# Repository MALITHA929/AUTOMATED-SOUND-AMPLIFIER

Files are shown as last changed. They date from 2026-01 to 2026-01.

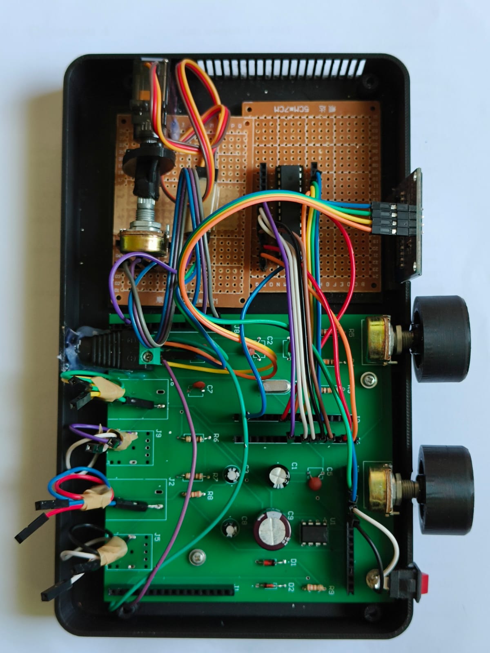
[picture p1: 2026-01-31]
images/WhatsApp Image 2026-01-30 at 5.55.49 PM.jpeg

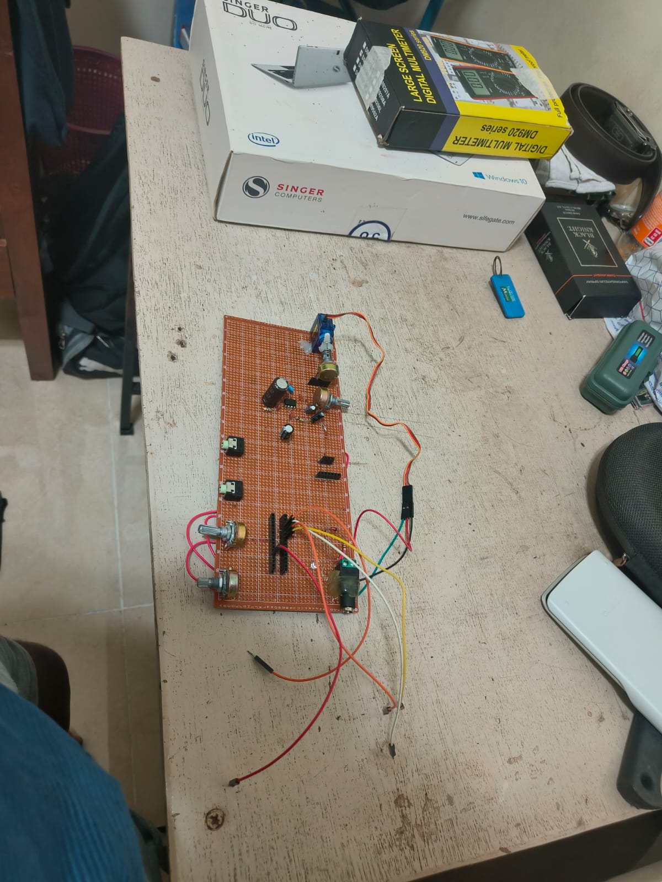
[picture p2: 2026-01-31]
images/WhatsApp Image 2026-01-30 at 5.51.47 PM_2.jpeg

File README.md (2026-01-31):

# 📢 Automated Sound Amplifier
Semester_02 project

The Automated Sound Amplifier is a standalone system that automatically maintains consistent audio levels in real time. It monitors the output of an existing amplifier, analyzes sound levels, and dynamically adjusts gain to ensure clear and balanced audio for different speakers.

Designed for lectures, meetings, and small events, the system integrates seamlessly with existing audio setups without requiring modifications. It also supports customizable calibration to adapt to different acoustic environments.

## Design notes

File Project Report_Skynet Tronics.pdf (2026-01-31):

## University of Moratuwa Faculty of Engineering Department of Electronic & Telecommunication Engineering

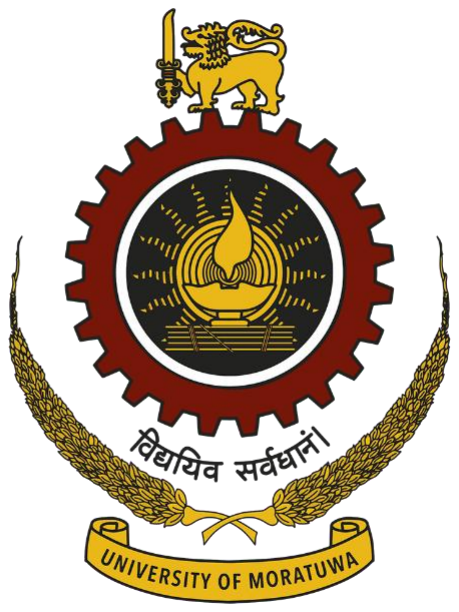
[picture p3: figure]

## EN1190 Engineering Design Project

# AUTOMATIC SOUND REGULATOR

by

## Skynet Tronics

230058N | H. A. P. Aroshana
230563H | H. D. J. D. Samaranayaka
230680M | W. M. H. Wanigasundara
230689A | A. H. T. M. Weerakoon

## Content

## 1. Problem Description

1.1 Problem

Effective communication is crucial when addressing an audience, ensuring that every

individual can clearly hear and understand the speaker. However, practical challenges arise due

to variations in speaking styles, voice levels, and acoustics. In situations where multiple people

speak, the ideal approach is to adjust the audio system for each speaker individually. However,

this typically requires a skilled audio technician, which may not always be practical or cost

effective. While hiring such a professional might be justified for large-scale events, common

scenarios like lectures, meetings, or small gatherings often rely on a single, fixed audio setting.

This can lead to uneven audibility. Some speakers may be too loud, while others may be

difficult to hear, resulting in communication gaps and reduced

1.2 Expected Goal

Our goal is to introduce a new device which regulates the output sound of an audio system

without damaging or reducing the quality of audio signal in an affordable price range. It enables

individuals and organizations to control their audio needs effortlessly.

1.3 Solution

To address the issue of fluctuating audio levels that impact communication clarity, we propose

the development of an external volume adjustment device. This system intelligently monitors

and adjusts the audio output from an existing amplifier without needing to replace or heavily

modify the current setup.

1.4 Justification of Selection

Although there are many amplifiers in the current market, there are many real-world issues.

such as being unaffordable, needing a dedicated person for controlling the device, lack of

expertise in sound system handling, etc. To validate the problem, we conducted a survey among

audio engineers, sound controllers, students and institutions that manage large audiences. The

feedback confirmed that fluctuating audio levels are a common issue. Also, we introduced our

solution, an automatic sound regulator. As positive feedback, our stakeholders emphasized the

need for a dynamic adjustment solution. Through the validation of the stakeholders, we, Skynet

Tronics, identified clear market demand for a dynamic audio controller.

## 2. Product Feasibility

2.1 Technical Feasibility

We have successfully demonstrated the technical feasibility of our project by completing the

necessary design, development, and testing phases. Key components were selected based on

performance, compatibility, and availability. A central processing unit was used to handle

core functionalities, including signal processing and system control. The device is powered

by a stable power source, with voltage regulation implemented to ensure reliable operation. A

custom PCB was designed to integrate all essential modules, improving both efficiency and

compactness. The external casing was developed using 3D printing to securely house internal

components and provide a professional finish. The final assembly and testing were carried

out in the digital lab. These steps confirm that all technical requirements were met, validating

the practical implementation of the proposed system.

2.2 Hardware Feasibility

The hardware components we used are

- Atmega328p microcontroller
- LM386N Op Amp
- 1.1’ OLED Display
- 3.5mm and 6.5mm input/ output ports
- 230V ac to 5V dc converter
- 3.5mm to 3.5mm connector
- 3.5mm to 6.35mm connector
2.3 | Software Feasibility
Software | Purpose
Altium Designer | PCB designing
Arduino | Programming atmega328p microcontroller
SolidWorks | Enclosure designing

## 3. Product Applications

The automatic sound regulator is designed to improve the clarity and consistency of audio in

various real-world applications. Especially, multiple speakers are involved in speaking, or the

same speaker is speaking for a long time. It is particularly useful in environments that lack a

dedicated audio technician. Moreover, continuous manual adjustment of volume is not

possible. Likewise, we identify several practical applications of our design.

- Lecture halls and classrooms: Different lecturers or students may speak at different voice levels.
- Business meetings and conferences: To ensure all participants are clearly heard without m less knowledge in sound handling, etc.anual intervention.
- Community events/ Religious gatherings: Multiple speakers or performers participate.
- Workshops and training sessions: Clear communication is essential for learning. Also speaking for a long time causes the volume of the speaker to reduce by the time.

Using an automatic sound regulator as an intermediate device in addition to the existing sound

systems offers an affordable, plug and play solution to maintain optimal audio levels. Its ability

to continuously monitor and adjust volume in real time helps reduce listener tiredness, prevents

communication breakdowns, and enhances the overall audience experience.

## 4. Product Architecture

The underlying architecture of our automatic sound controller is a very simple, easy to

understand. The main part of our product is amplification (amplification module). In addition

to this, we can identify controlling modules, power modules, input/ output modules basically.

The amplification module consists of an LM386N operational amplifier and a voltage divider

circuit. The op amp has a constant gain but varying input voltage. A servo motor which is

controlled according to the input sound signal has been used to operate a potentiometer and

generate the varying input of the op amp. That means a similar signal to input sound signal is

generated using the amplification module which is amplified or attenuated.

An atmega328P microcontroller as the central controller of the device. It continuously monitors

the input sound signal. First, it samples the input signal and calculates the average voltage of

the input sound signal. If the average voltage value exceeds the user-defined range, it changes

the overall gain by operating the servo motor.

As the power source, the device is powered by 5V dc source. Therefore, we use a 230V ac to

5V dc converter.

To give input signal and bring output signal, there are two types of port in the input/ output

interface (3.5mm, 6.35mm). That increases the versatility of the regulator and customer

satisfaction. 1.1’ OLED display is used as the main external output to give a attractive user

experience. Additionally, there is a power on/off indicator.

## 5. Product Specifications

Specification | Description
Type | Automatic sound regulator
Dimensions | 20cm x 15cm x 5cm
Weight | 300 g
Power Supply | 230V to 5V converter included
Power Input | 5V, 85mA
Supported Port Types | 3.5mm, 6.35mm
Connectors | 3.5mm connecting wires included
Display | 1.1” OLED Display
Indictors | ON/ OFF indicator
Features | Automatic gain adjustment Enhanced sound control efficiency User-friendly display Low power usage Support for multiple port types Durable controlling switches, ports, knobs Small and light weight design Easy to use (Plug & Play)

## 6. PCB Design

Altium PCB designs of 2-layer printed circuit board.

6.1 Schematic design

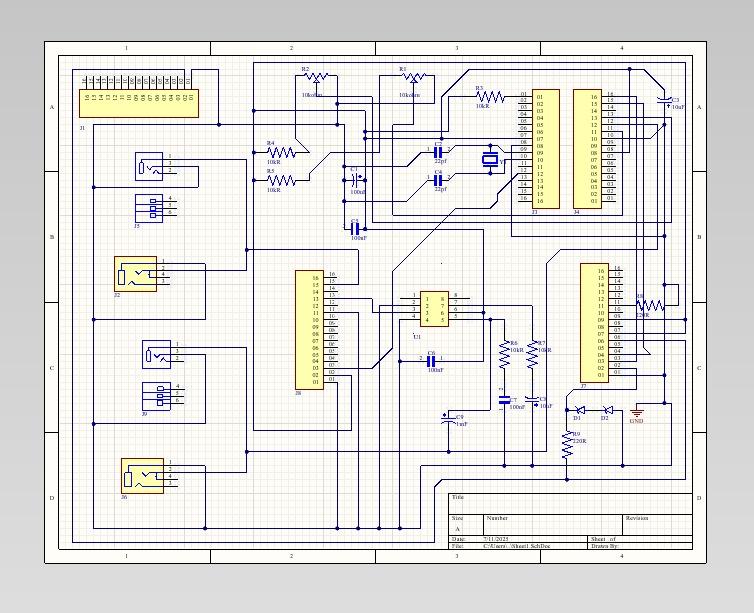
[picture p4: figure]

6.2 PCB layout

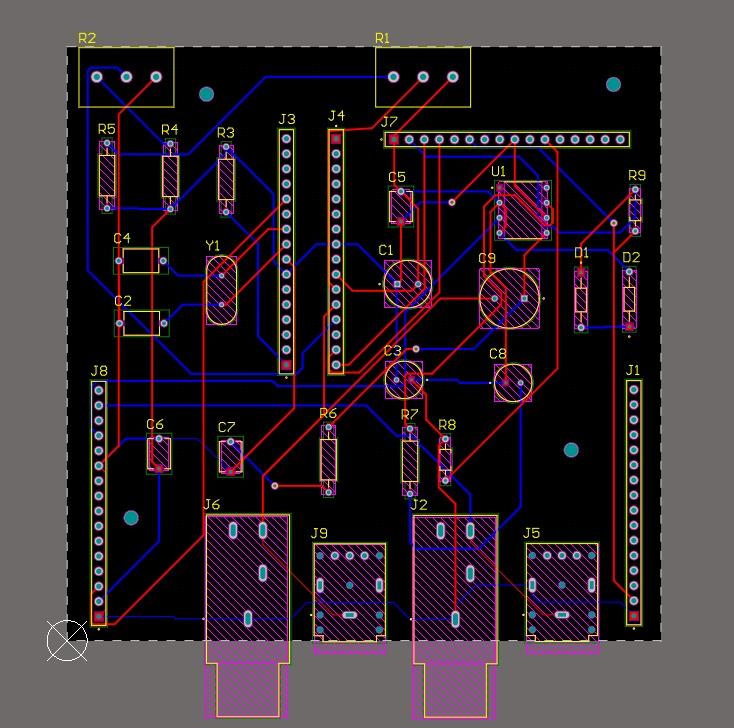
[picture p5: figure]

## 7. Product Enclosure

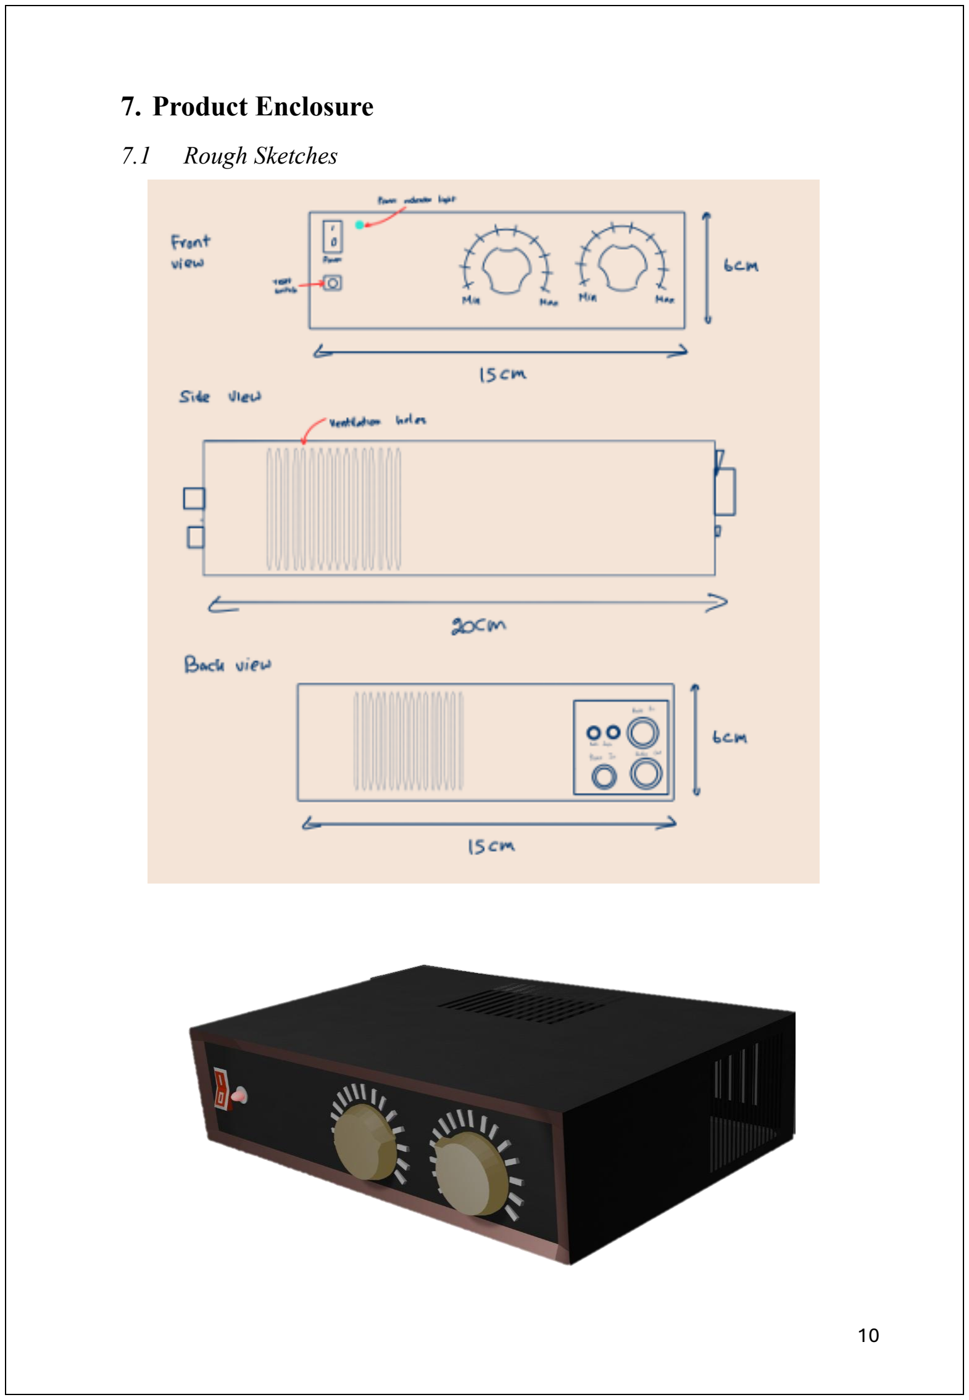
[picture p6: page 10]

7.1 Rough Sketches

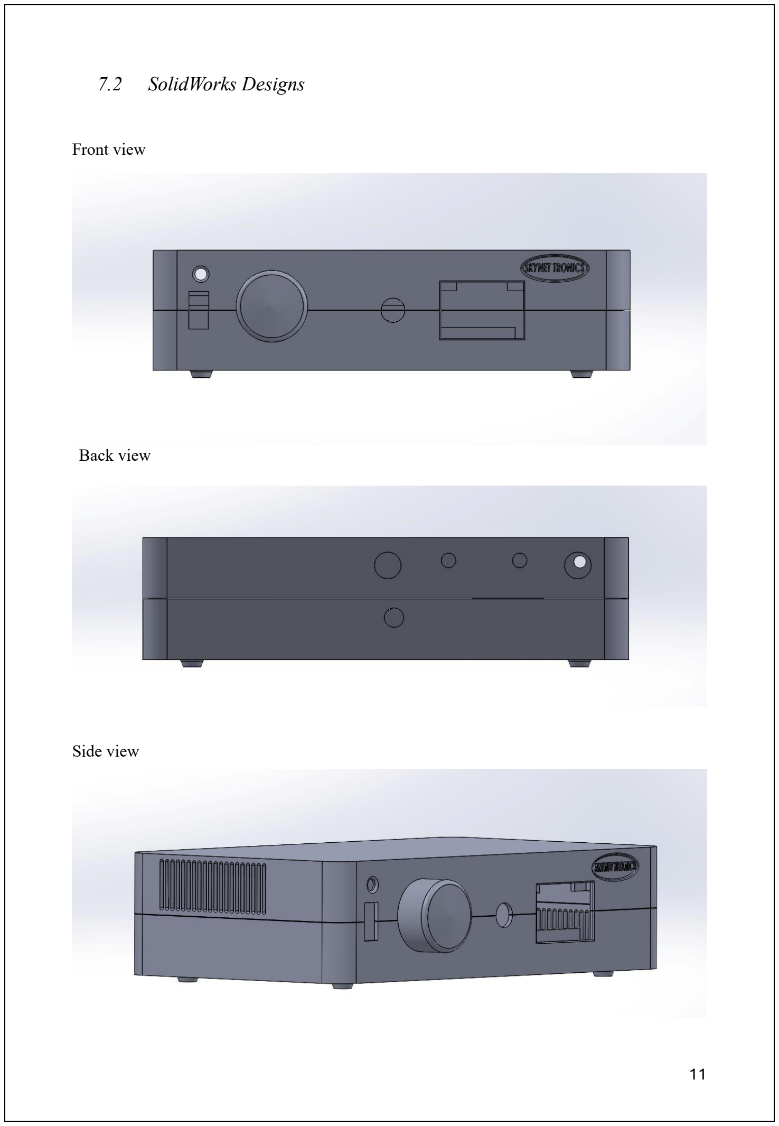
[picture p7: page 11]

7.2 SolidWorks Designs

Front view

Back view

Side view

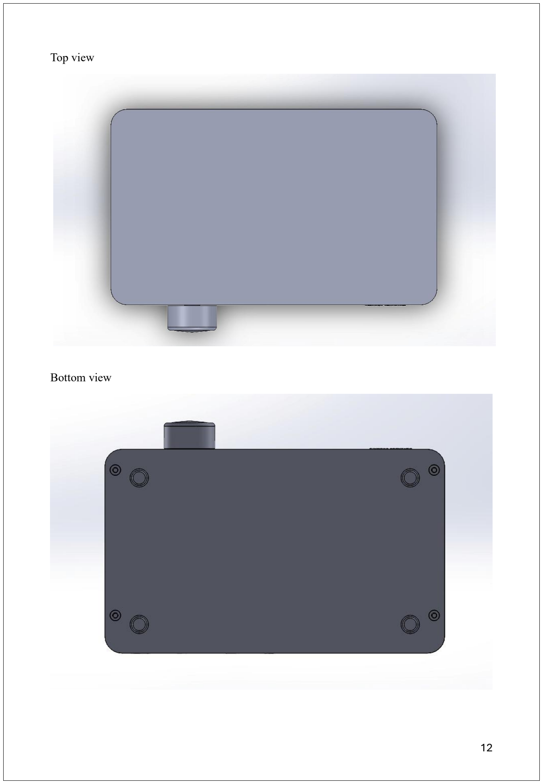
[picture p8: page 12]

Top view

Bottom view

## 8. Final Product

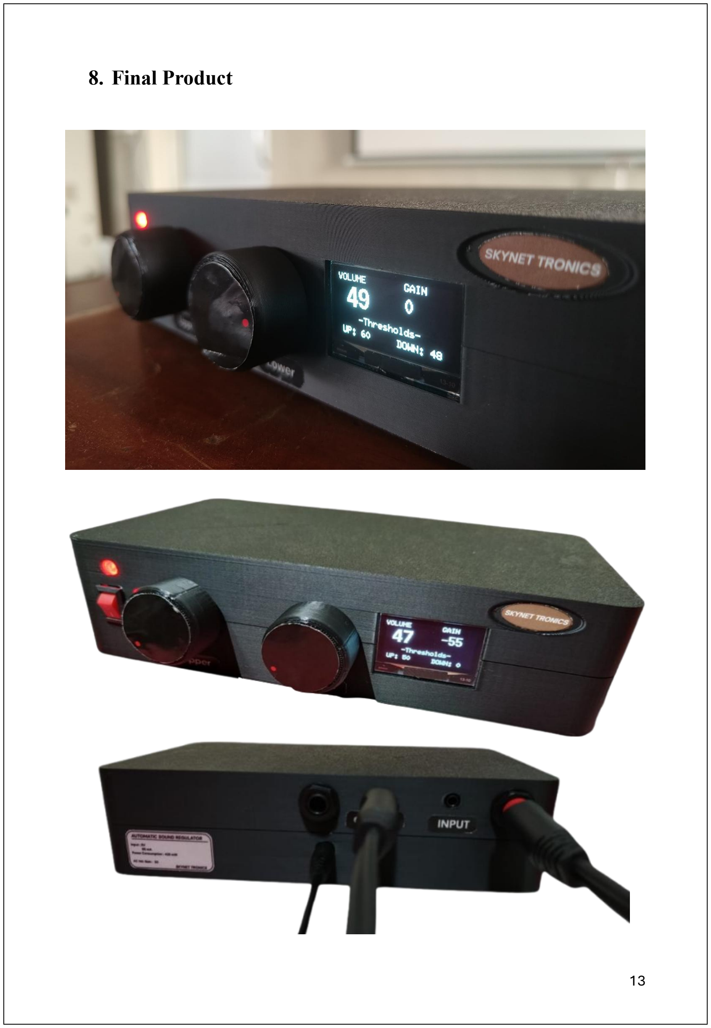
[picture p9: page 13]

## 9. Market Analysis

Our sound regulator is in the category of electronic amplification device which holds huge

capacity for the market in sound engineering. In the market there are several types of amplifiers

such as power amplifiers, pre-amplifiers, etc. We are different from those common

amplification devices. Because our intention is to design an intermediate device to sound

controlling in pre-defined range.

Our stakeholders are sound engineers, audio controllers, academic institutions, students,

speakers, government authorities, event organizers, etc. According to our analysis, our target

market is growing day by day.

There are many competitors in the market with a competitive selling price between LKR 20000

to LKR 100000. However, in our problem identification, we realized that it is difficult to afford

such an amount of money for a simple sound regulator. Moreover, some imported devices are

not compatible with local devices. For example, issues with connecting devices. Some devices

have additional features which are not useful and not worth money.

As a solution, Skynet Tronics is introducing a real-time, affordable, simple sound regulator. To

compete with the market, it has many features as well. Such features are good sound quality,

high sensitivity, user friendly display.

## 10. Final Budget

A full review of our budget is presented below. We identified that the cost of designing a single

unit is high, mainly due to shipping expenses and the inefficiency of 3D printing in terms of

cost. Therefore, we provide the estimated unit cost for mass production. We expect to reduce

costs by importing a large number of PCBs at once to minimize shipping expenses.

Additionally, we plan to use molding instead of 3D printing during mass production.

Expenses | Cost in Product Designing (LKR) | Cost Per Unit in Mass Production (LKR)
PCB manufacturing and shipping | 3000 | 500
Enclosure designing | 7500 | 2000
Components/ Assembling | 4500 | 2750
Warehouse and Transportation | 1000 | 100
Marketing | - | 50
Additional costs | - | 600
Total cost | 16000 | 6000

The total cost of a unit is LKR 6,000. With an 80% profit margin, we plan to price our

product at LKR 10,800.

Total Cost | Profit Margin | Final Price
LKR 6000 | 80% | LKR 10800

## 11. Future Developments

We, Skynet Tronics are planning to develop our product to improve and give a high-quality

outcome to the user. Initially, we are focusing on increasing the sound quality of the Automatic

Sound Regulator. As a part of this, we come up with some ideas to reduce the noise effect. Such

as separate the power supply module and the amplification module, using high quality

components, clean and clear soldering, etc.

In addition to that there is an intention to apply AI/ ML advanced technologies to recognize the

patterns in input signal, so that they improve regulating operation. For example, self-threshold

defining. Currently our device cannot handle sudden spikes of sound since we are relying on

an average value of input voltages. Therefore, our goal is to optimize our device to handle

sudden spikes of sound by identifying such conditions and reducing the response timing.

## 12. Task Allocation

Skynet Tronics is a group of four undergraduates from the University of Moratuwa. First, we

identified several problems with the intention of developing a solution. Then we selected one

problem worth solving and validated it through discussions with stakeholders. Meanwhile, we

developed and presented our solution to stakeholders and validated it. After that, we started

building the device by allocating parts of the product development process among us.

Name | Task
A. H. T. M. Weerakoon | Circuit designing, Soldering
W. M. H. Wanigasundara | Circuit analysis, Programming
H. D. J. D. Samaranayaka | PCB designing, Assembling
H. A. P. Aroshana | Enclosure designing, Market review
- END -

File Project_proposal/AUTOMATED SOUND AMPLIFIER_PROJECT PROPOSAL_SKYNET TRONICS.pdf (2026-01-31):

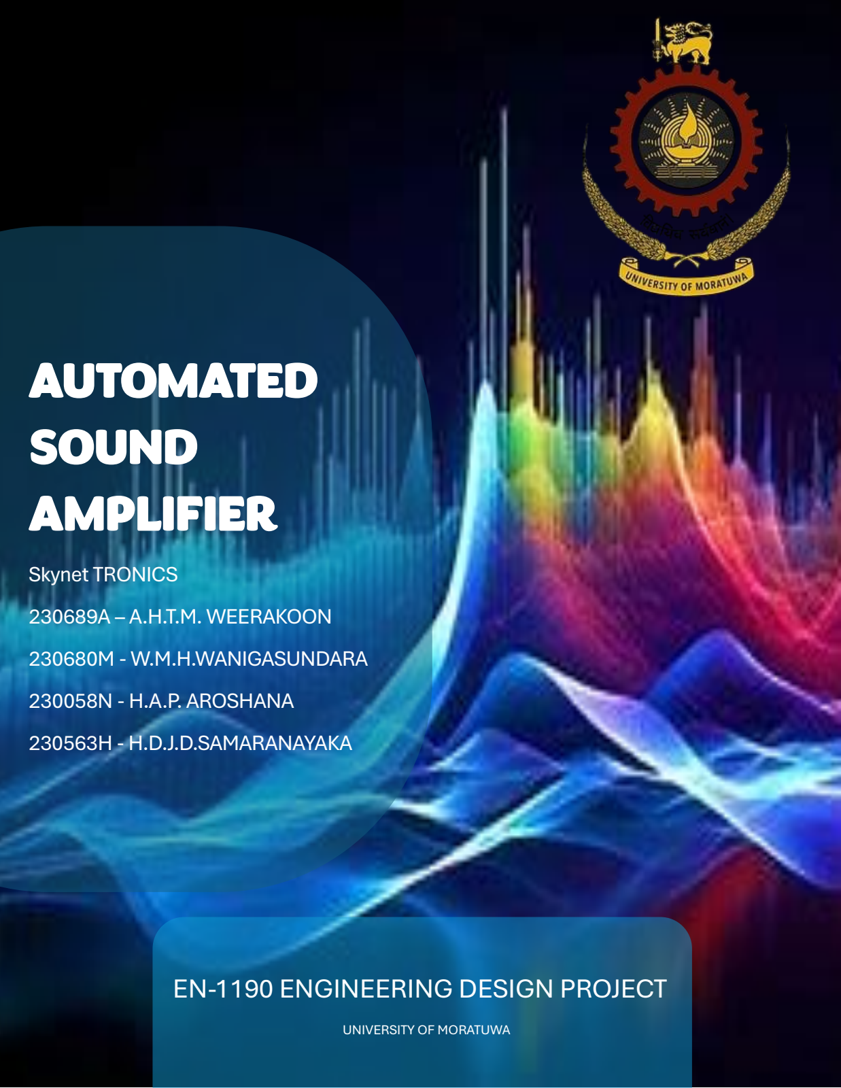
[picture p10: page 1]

# AUTOMATED SOUND AMPLIFIER

## Skynet TRONICS 230689A – A.H.T.M. WEERAKOON 230680M - W.M.H.WANIGASUNDARA 230058N - H.A.P. AROSHANA 230563H - H.D.J.D.SAMARANAYAKA

# EN-1190 ENGINEERING DESIGN PROJECT

UNIVERSITY OF MORATUWA

# PROBLEM

Solution | Stakeholder Review

# Uniqueness and Limitations

Effective communication is crucial when addressing an audience, ensuring that every individual can clearly hear and understand the speaker. However, practical challenges arise due to variations in speaking styles, voice levels, and acoustics.

In situations where multiple people speak, the ideal approach is to adjust the audio system for each speaker individually. However, this typically requires a skilled audio technician, which may not always be practical or cost-effective. While hiring such a professional might be justified for large-scale events, common scenarios like lectures, meetings, or small gatherings often rely on a single, fixed audio setting. This can lead to uneven audibility—some speakers may be too loud, while others may be difficult to hear—resulting in communication gaps and reduced audience engagement.

To address the issue of fluctuating audio levels that impact communication clarity, we propose the development of an external volume adjustment device. This system intelligently monitors and adjusts the audio output from an existing amplifier without needing to replace or heavily modify the current setup.

1.

2.

3.

5.

4.

key components:

Signal Monitoring Unit – continuously samples the output signal from the main amplifier.

Threshold Analysis Module – determines whether the current audio level is within an acceptable range.

Dynamic Gain Adjustment Unit – adjust the audio to maintain optimal clarity

Configuration and Calibration Setup – customizes the system for different environments

Compact and Modular Hardware Design – ensures the solution is easy to integrate with existing audio setups.

We conducted a survey among audio engineers, sound controllers, students, and institutions managing large audiences. The feedback confirmed that fluctuating audio levels are a common issue, emphasizing the need for a dynamic adjustment solution.

To gather further insights, we invite you to complete our brief feedback form

Our solution stands out by offering an external, standalone device that dynamically adjusts audio levels without modifying the existing amplifier system. Unlike many current products with fixed thresholds, our design supports customizable calibration for different environments. However, limitations include the need for initial test runs to determine optimal thresholds, the assumption of relatively stable environmental conditions, and dependency on the quality and characteristics of the existing audio system — such as the responsiveness of the amplifier and the dynamic range of the speakers — which may affect overall performance.

Overall flaw of the system.

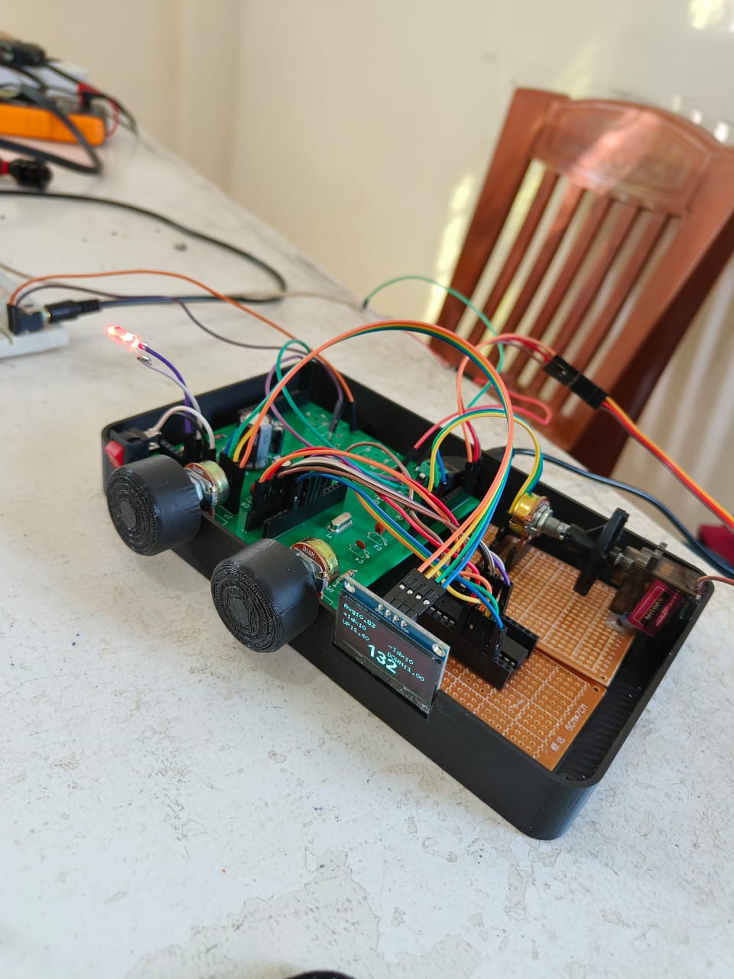
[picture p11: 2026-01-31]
images/WhatsApp Image 2026-01-30 at 5.55.41 PM.jpeg

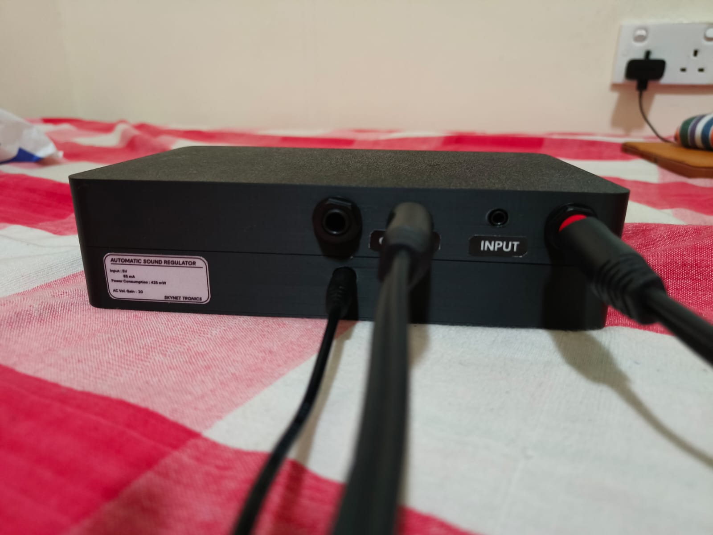
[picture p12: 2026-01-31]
images/WhatsApp Image 2026-01-30 at 5.56.28 PM.jpeg

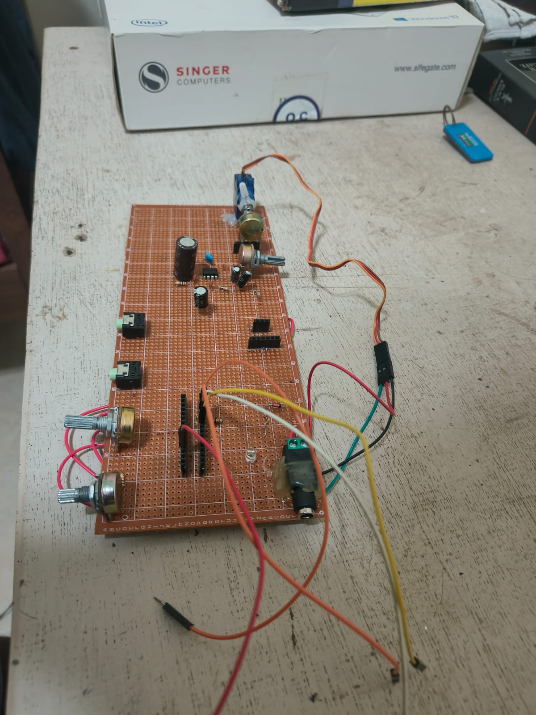
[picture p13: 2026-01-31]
images/WhatsApp Image 2026-01-30 at 5.51.47 PM.jpeg

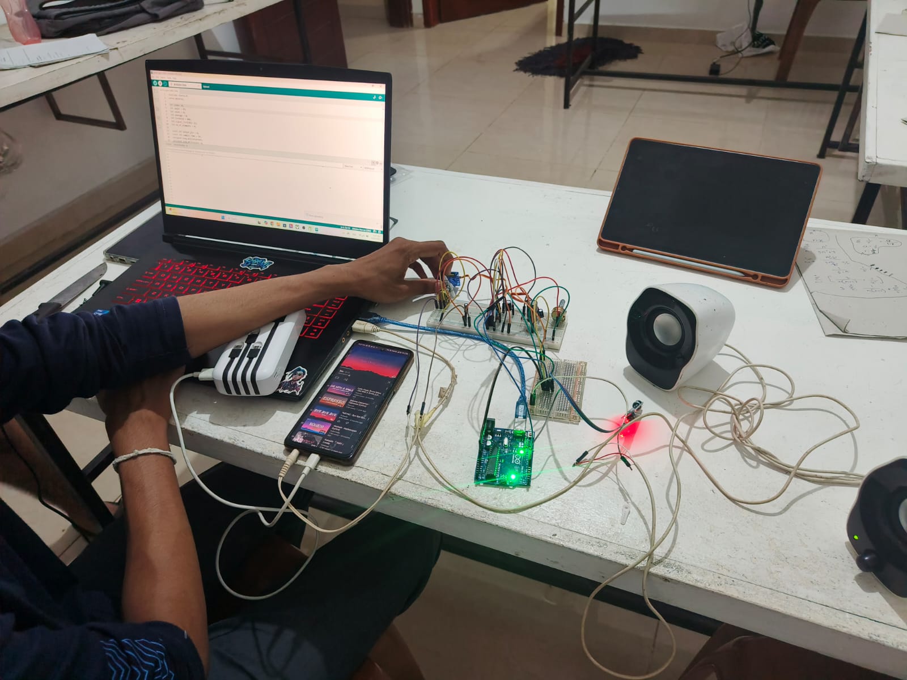
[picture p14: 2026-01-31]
images/WhatsApp Image 2026-01-30 at 5.56.29 PM.jpeg

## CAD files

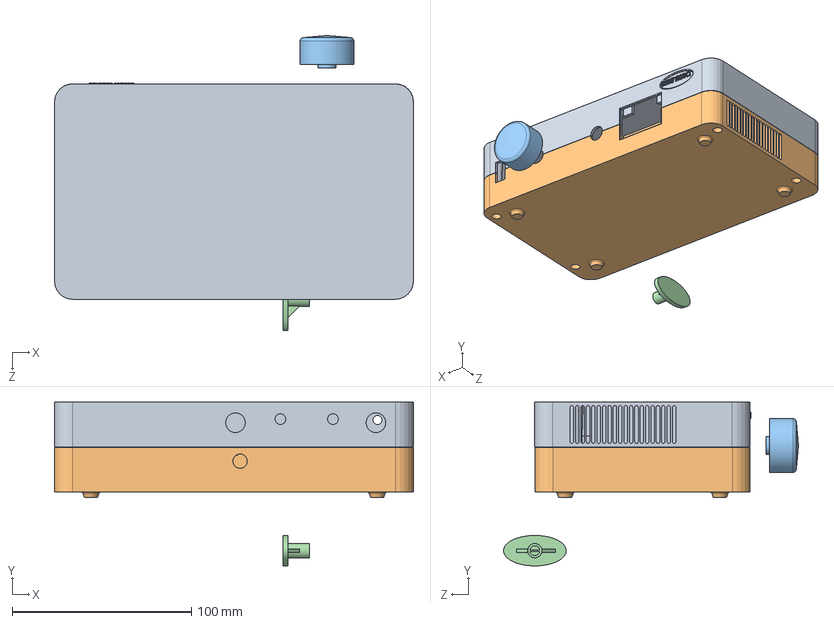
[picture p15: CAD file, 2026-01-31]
Enclosure_files/Assem2.SLDASM
200.1 x 91.3 x 164.4 mm
servocap

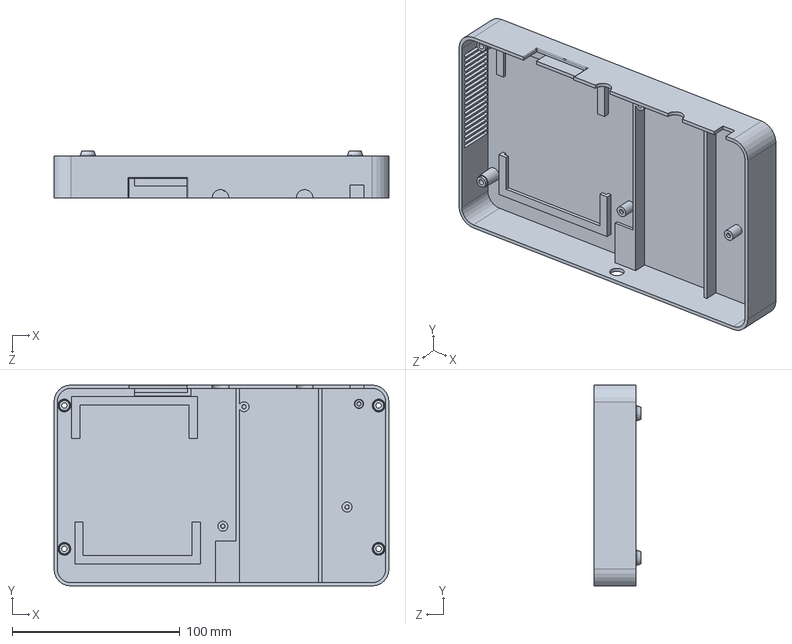
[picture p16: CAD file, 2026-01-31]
Enclosure_files/Body10 (1).SLDPRT
200.0 x 120.0 x 28.0 mm

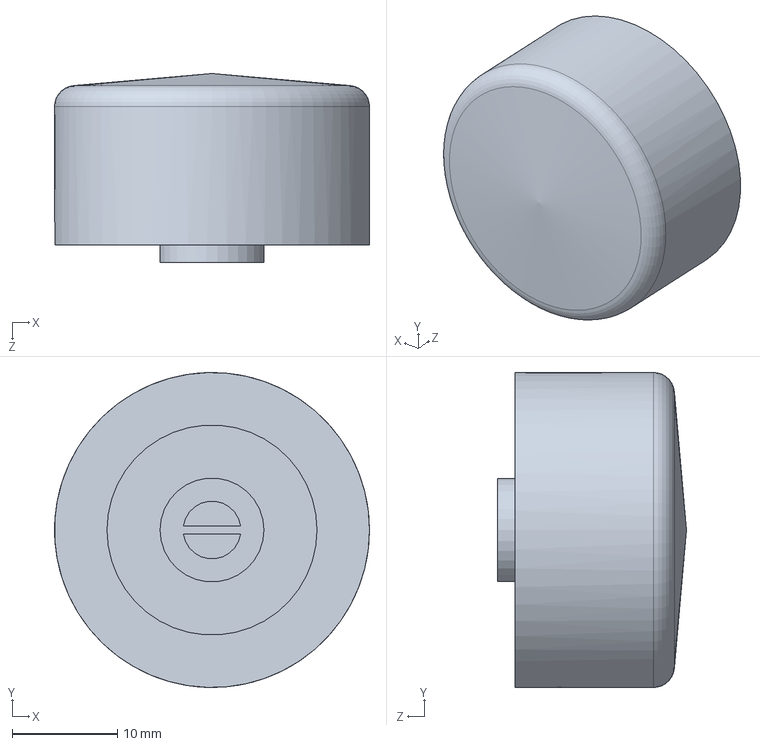
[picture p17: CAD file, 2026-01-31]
Enclosure_files/Part1 (2).SLDPRT
30.0 x 30.0 x 18.0 mm

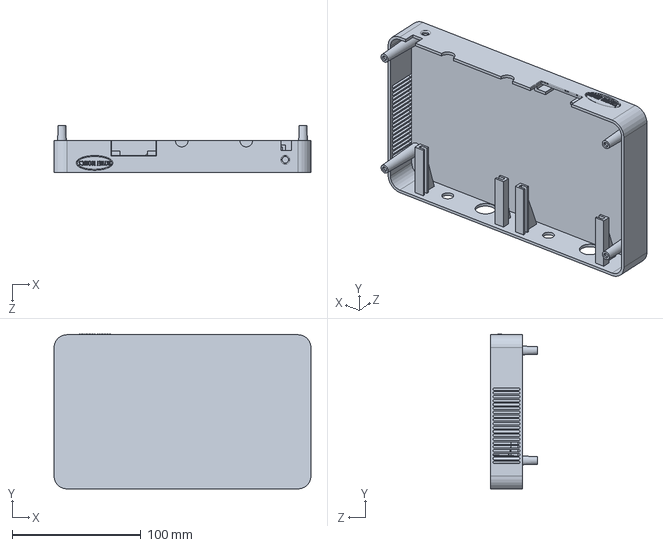
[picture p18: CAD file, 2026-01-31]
Enclosure_files/Body6 (2).SLDPRT
200.0 x 120.5 x 36.7 mm
